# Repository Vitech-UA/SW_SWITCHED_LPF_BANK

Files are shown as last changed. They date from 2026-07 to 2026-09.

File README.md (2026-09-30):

# HF_SWITCHED_LPF_BANK

Плата перемикального банку ФНЧ для КХ-підсилювача потужністю до 250 Вт.

## Підтримувані діапазони

- 80 м (3,6 МГц)
- 40 м (7,2 МГц)
- 20 м (14 МГц)
- 15 м (21 МГц)

## Живлення (роз'єм X4)

- Напруга живлення плати: 12–24 В.
- Споживання: не більше 100 мА.

## Керування (роз'єм X3)

| Діапазон | Частота | A | B | C | D | Код ABCD |
|:---:|---:|:---:|:---:|:---:|:---:|:---:|
| 80 м | 3,5 МГц | 1 | 0 | 0 | 0 | `1000` |
| 40 м | 7 МГц | 0 | 1 | 0 | 0 | `0100` |
| 20 м | 14 МГц | 0 | 0 | 1 | 0 | `0010` |
| 15 м | 21 МГц | 0 | 1 | 1 | 0 | `0110` |

---

## Розрахунок ФНЧ для КХ-діапазонів

Для розрахунків використано онлайн-калькулятор [LC Filter Design Tool](https://markimicrowave.com/technical-resources/tools/lc-filter-design-tool/) від Marki Microwave.

### Результати розрахунків

| Діапазон | Частота розрахунку | Результат |
|:---:|:---:|:---:|
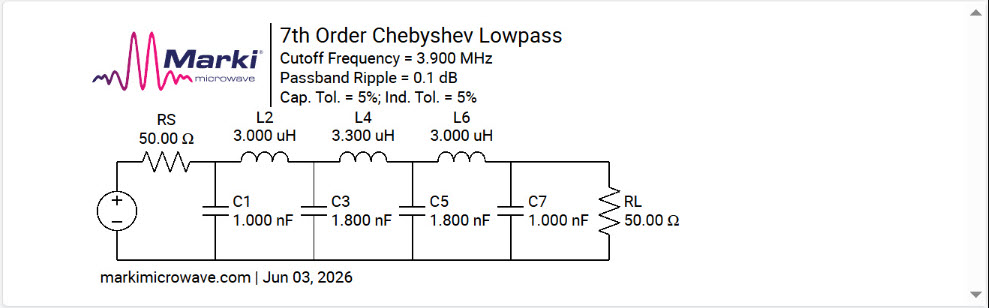
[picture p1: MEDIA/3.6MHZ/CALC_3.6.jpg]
ФНЧ 3,6 МГц
| **80 м** | 3,6 МГц |  |
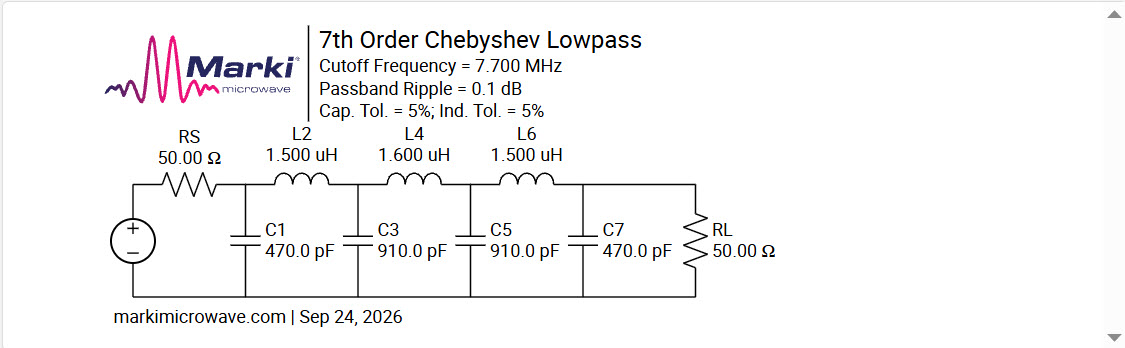
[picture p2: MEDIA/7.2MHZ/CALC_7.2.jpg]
ФНЧ 7,2 МГц
| **40 м** | 7,2 МГц |  |
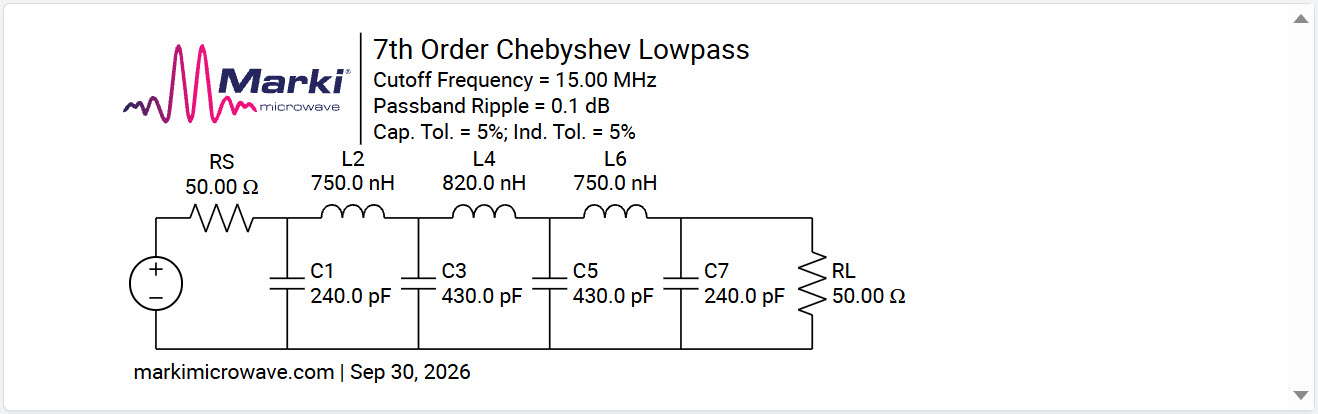
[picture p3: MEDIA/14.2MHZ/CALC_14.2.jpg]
ФНЧ 14,2 МГц
| **20 м** | 14 МГц |  |
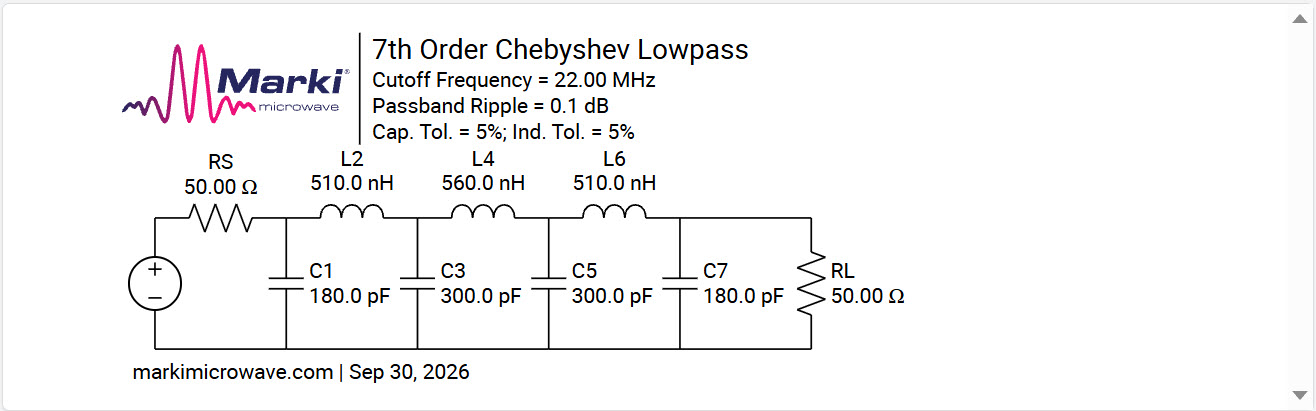
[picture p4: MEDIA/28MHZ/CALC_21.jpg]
ФНЧ 21 МГц
| **15 м** | 21 МГц |  |

---

## Зовнішній вигляд

| Верхня сторона плати | Верхня сторона без компонентів | Нижня сторона |
|:---:|:---:|:---:|
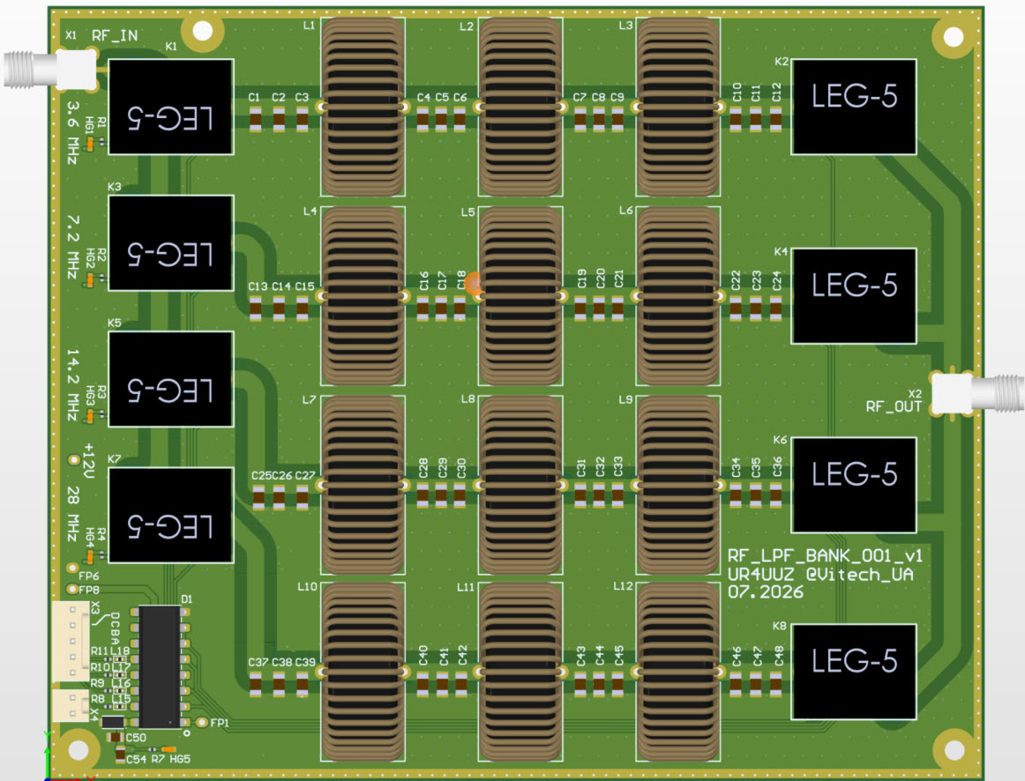
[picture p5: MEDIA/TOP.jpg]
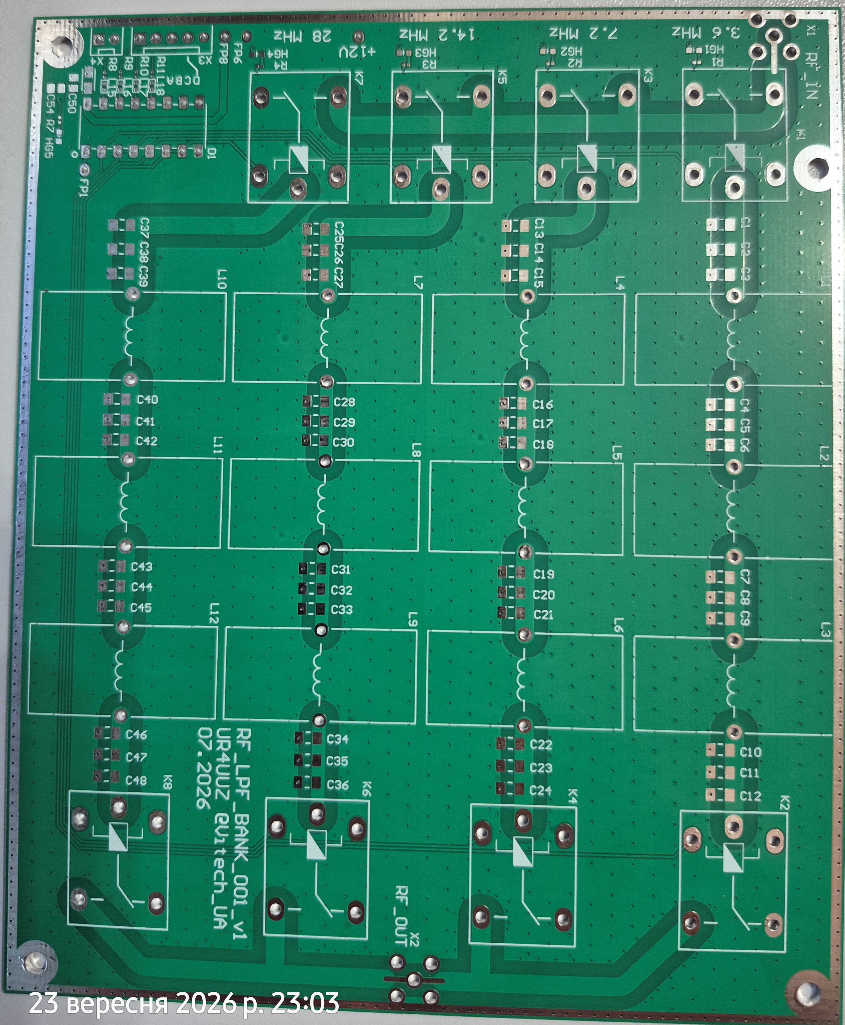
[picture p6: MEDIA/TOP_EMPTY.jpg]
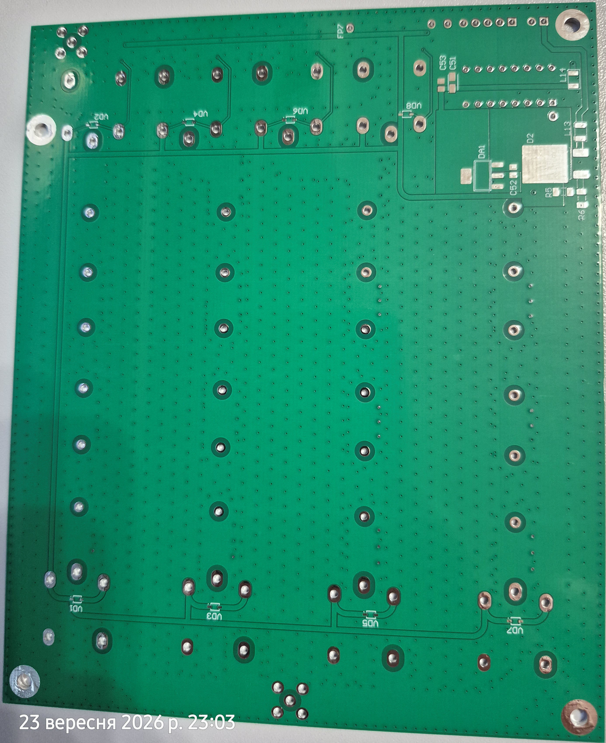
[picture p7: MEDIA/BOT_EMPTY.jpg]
|  |  |  |

## Збірка (без L та C)

| Верхня сторона | Нижня сторона |
|:---:|:---:|
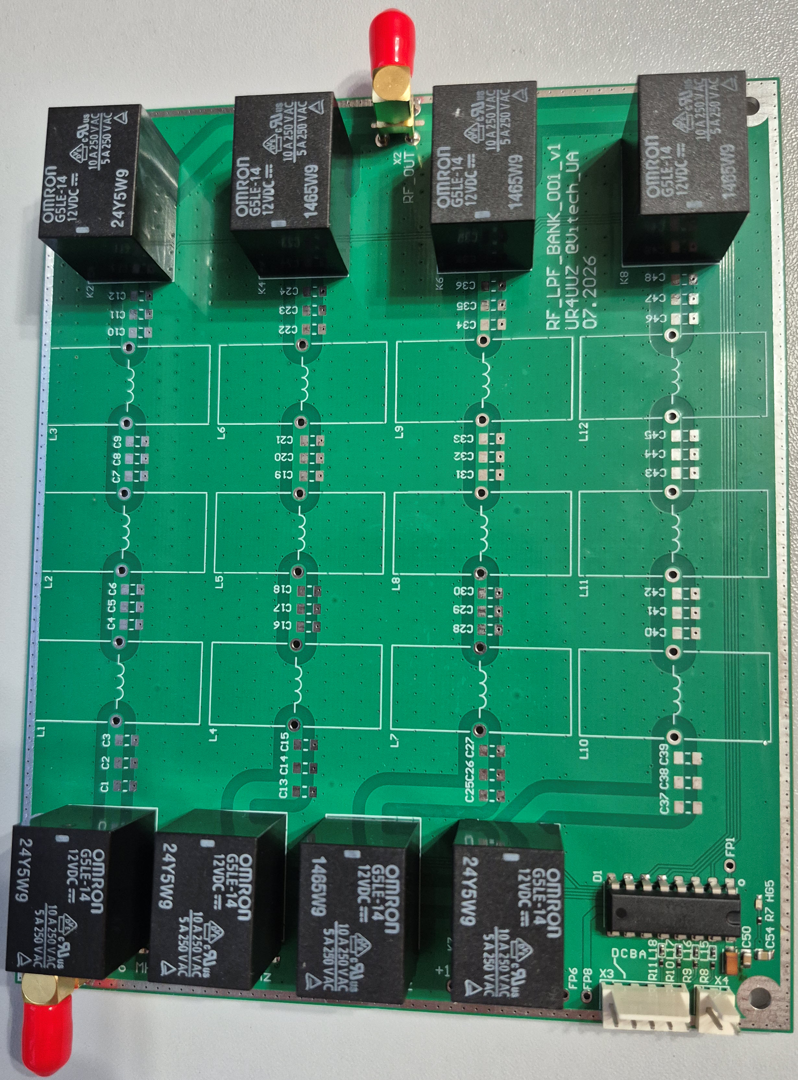
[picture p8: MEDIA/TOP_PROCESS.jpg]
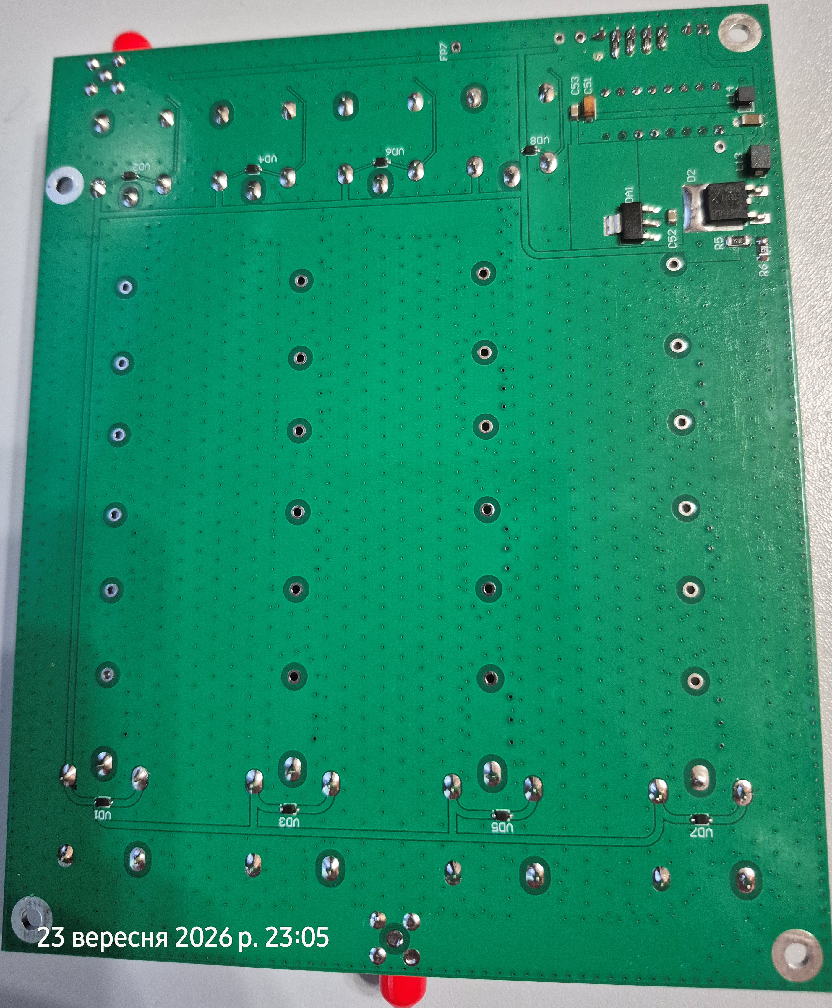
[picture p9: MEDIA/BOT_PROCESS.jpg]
|  |  |

---

## Налаштування та результати вимірювань ФНЧ

### 1. ФНЧ 80 м — 3,6 МГц

<details>
<summary><b>Переглянути налаштування та результати вимірювань</b></summary>

#### Налаштування

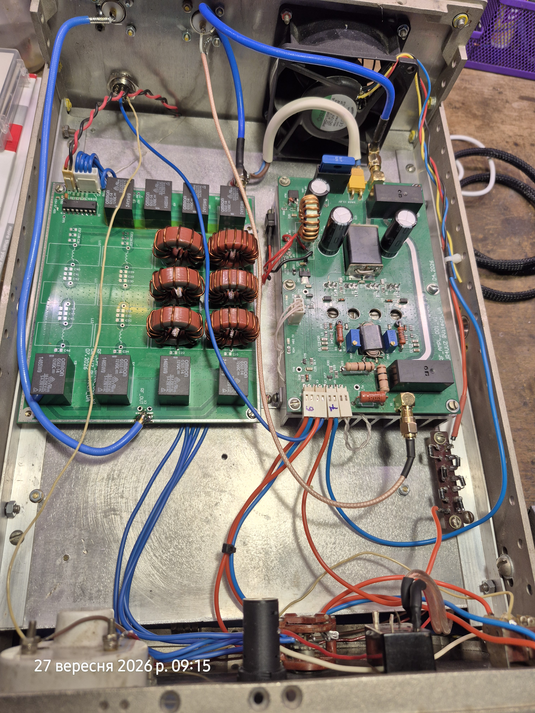
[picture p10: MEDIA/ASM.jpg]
Налаштування


#### Результати вимірювань

**S21 — Передача**

Коефіцієнт передачі у смузі пропускання 3,5–3,7 МГц не менше −0,009 дБ. На частоті 7,2 МГц — не більше −52 дБ.

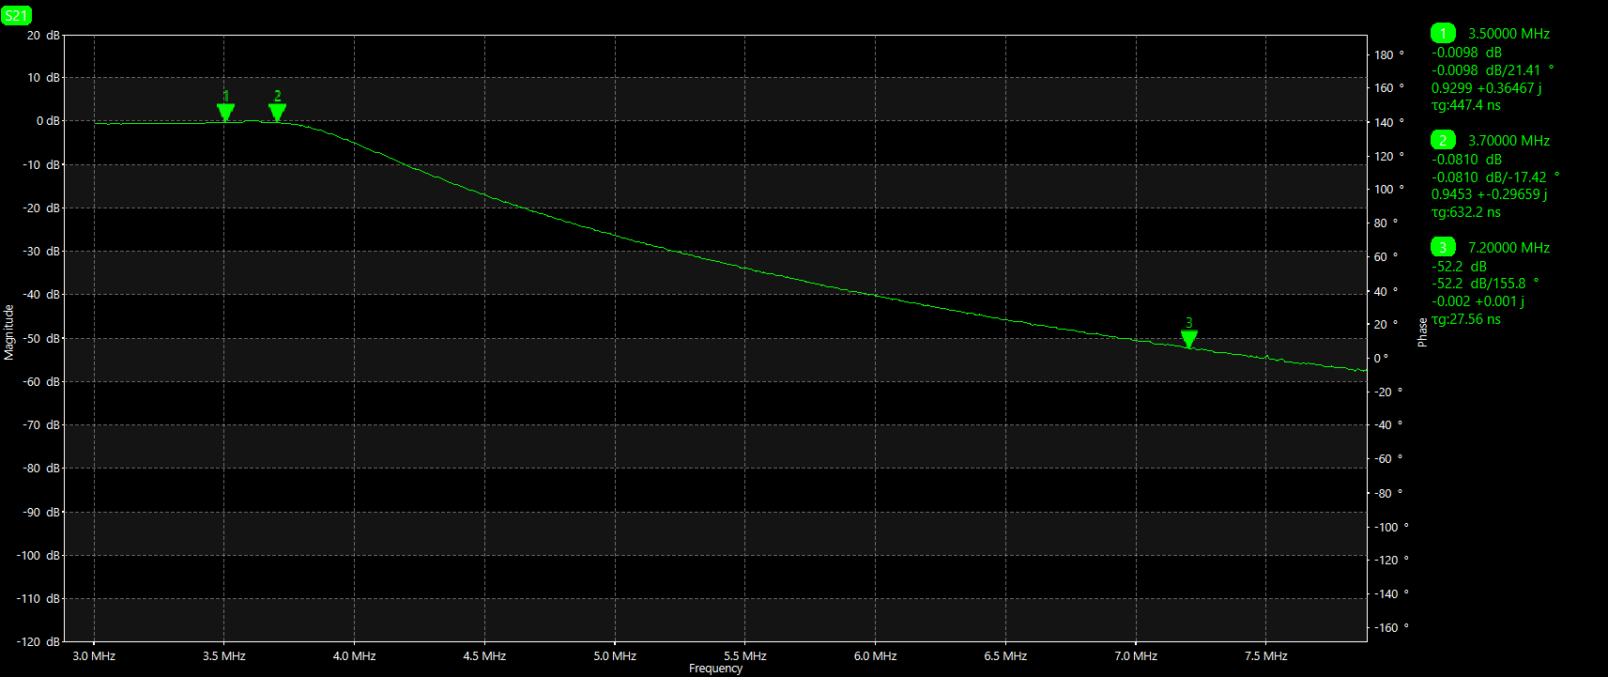
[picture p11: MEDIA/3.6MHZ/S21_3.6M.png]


**S11 — Відбиття**

КСХН у смузі пропускання 3,5–3,7 МГц не більше 1,8.

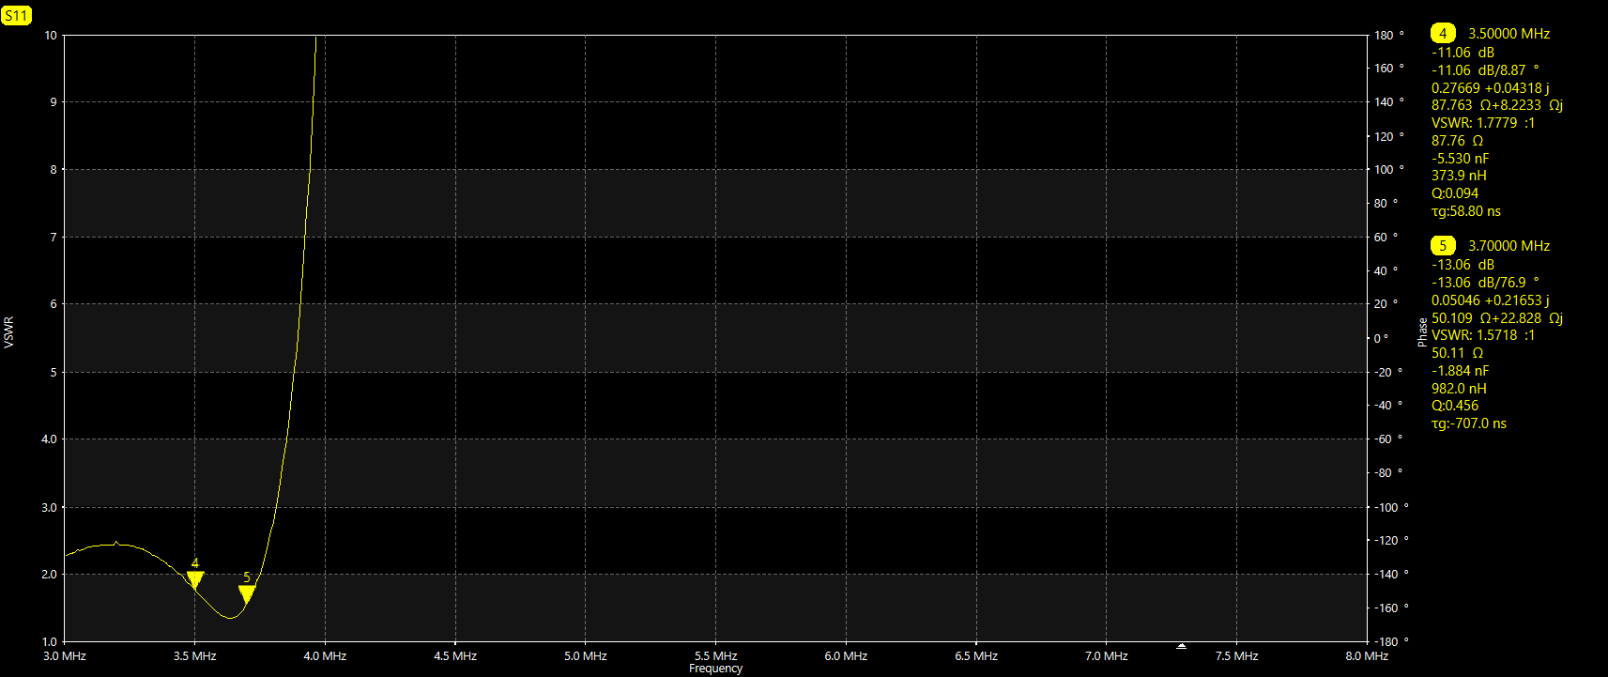
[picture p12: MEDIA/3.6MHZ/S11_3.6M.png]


</details>

### 2. ФНЧ 40 м — 7,2 МГц

<details>
<summary><b>Переглянути налаштування та результати вимірювань</b></summary>

#### Налаштування

| Етап 1 | Етап 2 |
|:---:|:---:|
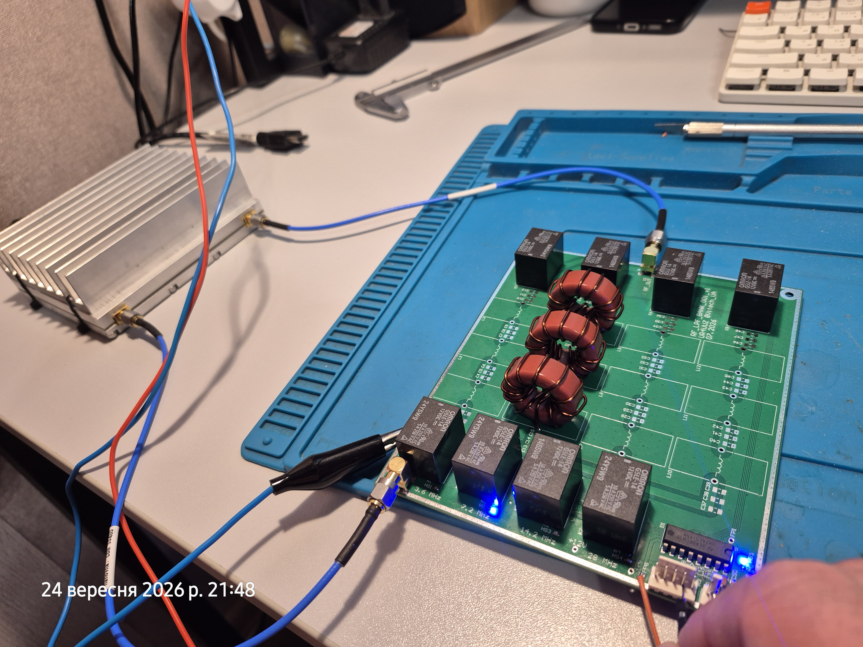
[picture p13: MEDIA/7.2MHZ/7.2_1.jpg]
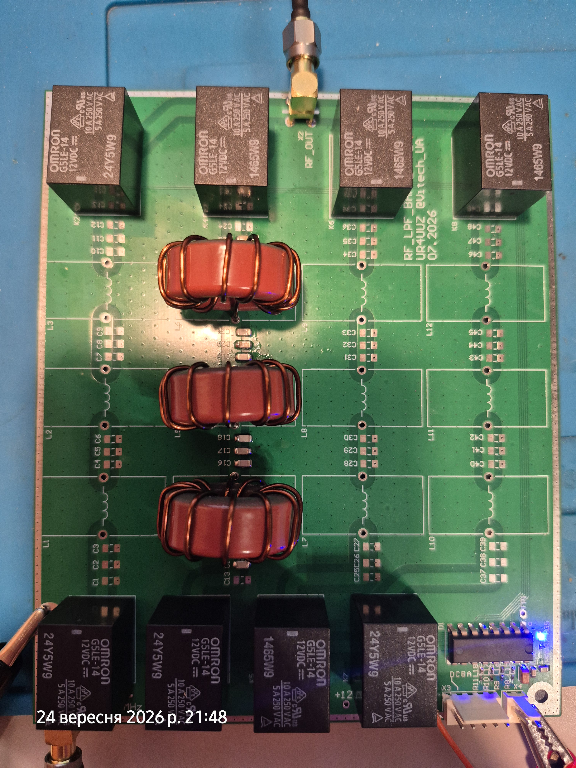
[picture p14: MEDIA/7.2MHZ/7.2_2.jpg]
|  |  |

#### Результати вимірювань

**S21 — Передача**

Коефіцієнт передачі у смузі пропускання 7–7,2 МГц не менше −0,3 дБ. На частоті 14 МГц — не більше −55 дБ.

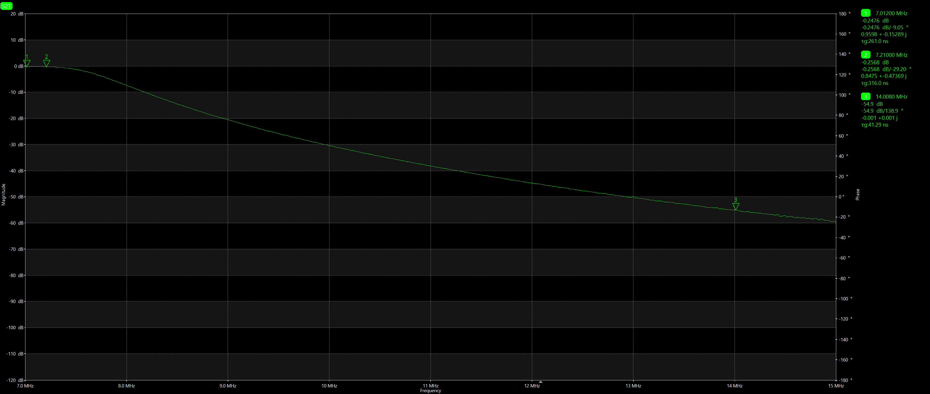
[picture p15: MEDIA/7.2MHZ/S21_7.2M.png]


**S11 — Відбиття**

КСХН у смузі пропускання 7–7,2 МГц не більше 1,3.

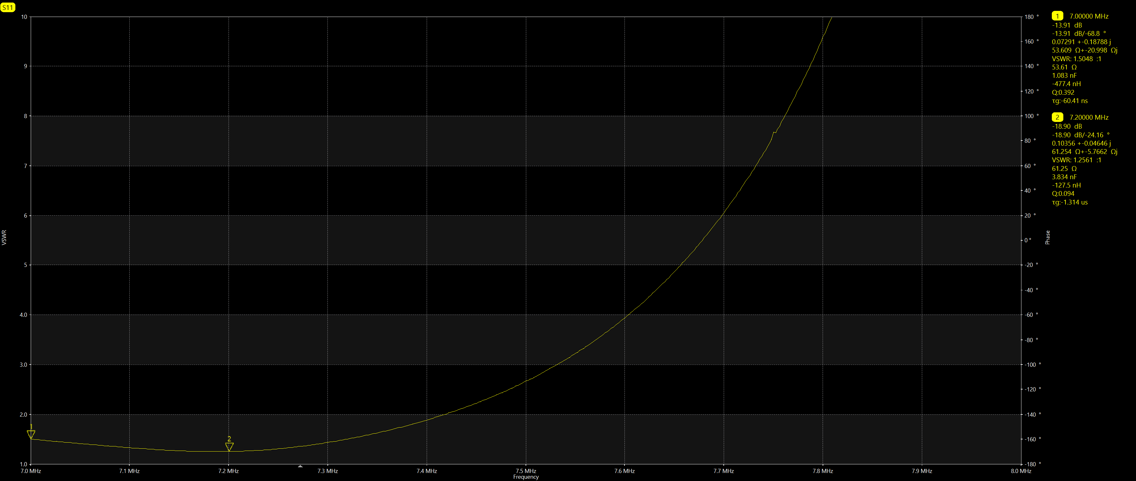
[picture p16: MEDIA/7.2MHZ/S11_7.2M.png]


</details>

### 3. ФНЧ 20 м — 14 МГц

<details>
<summary><b>Переглянути налаштування та результати вимірювань</b></summary>

#### Налаштування

| Етап 1 | Етап 2 |
|:---:|:---:|
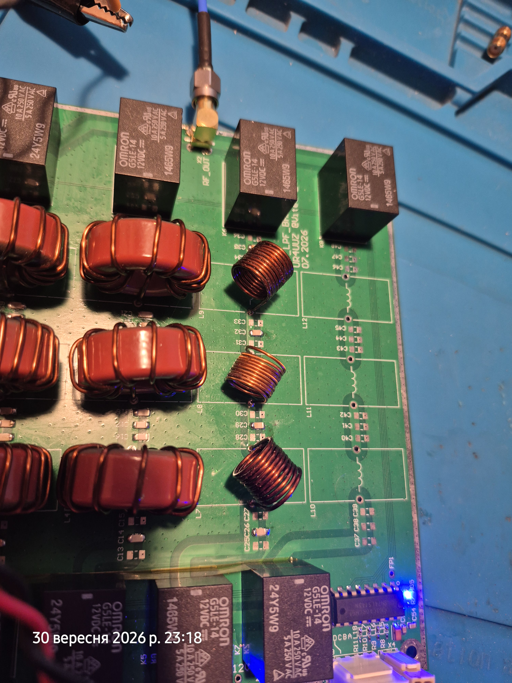
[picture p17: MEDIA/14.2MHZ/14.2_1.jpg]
|  |  |

#### Результати вимірювань

**S21 — Передача**

Коефіцієнт передачі у смузі пропускання 14–14,3 МГц не менше −0,4  дБ. На частоті 28 МГц — не більше −55 дБ.

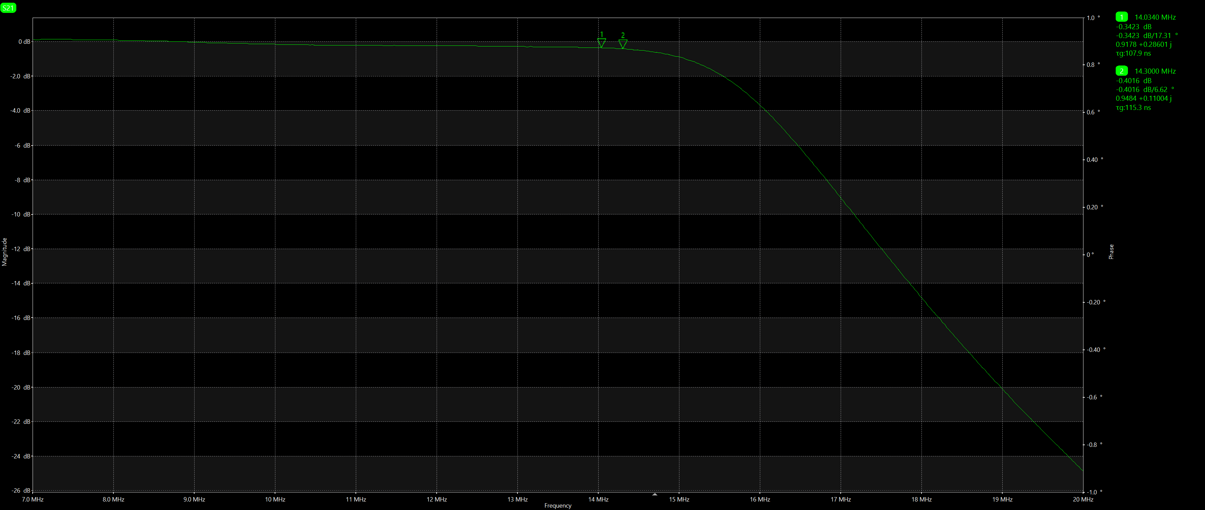
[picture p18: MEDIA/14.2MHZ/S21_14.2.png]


**S11 — Відбиття**

КСХН у смузі пропускання 14–14,2 МГц не більше 1,26.

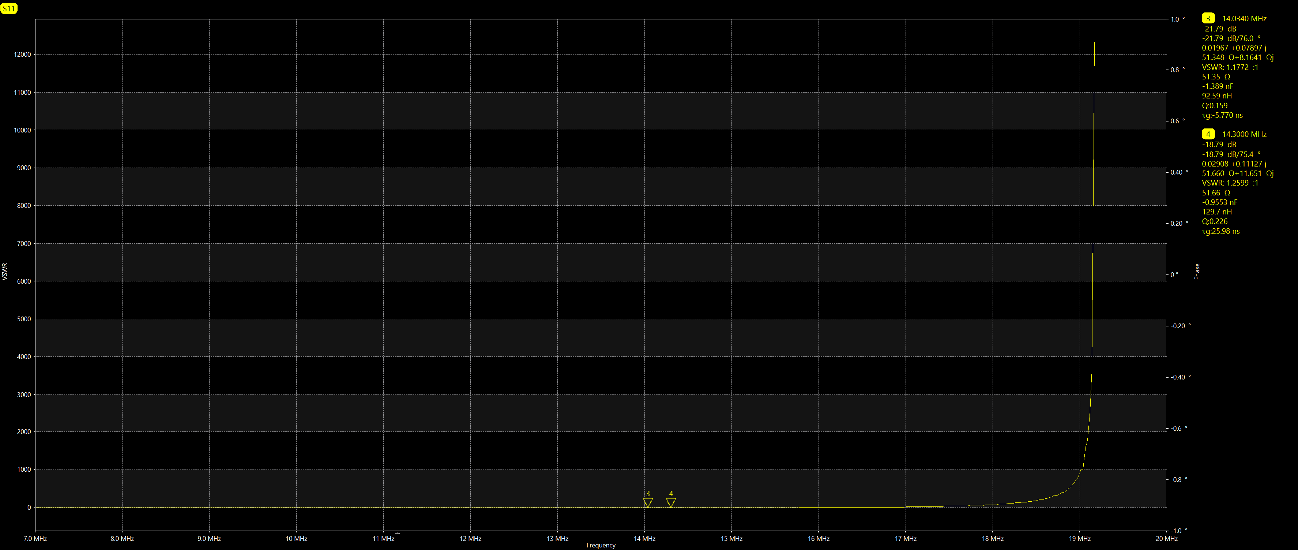
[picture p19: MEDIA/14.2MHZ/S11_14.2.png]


</details>

### 4. ФНЧ 15 м — 21 МГц

<details>
<summary><b>Переглянути налаштування та результати вимірювань</b></summary>

#### Налаштування

*Фото буде додано.*

#### Результати вимірювань

**S21 — Передача**

*Буде додано.*

**S11 — Відбиття**

*Буде додано.*

</details>

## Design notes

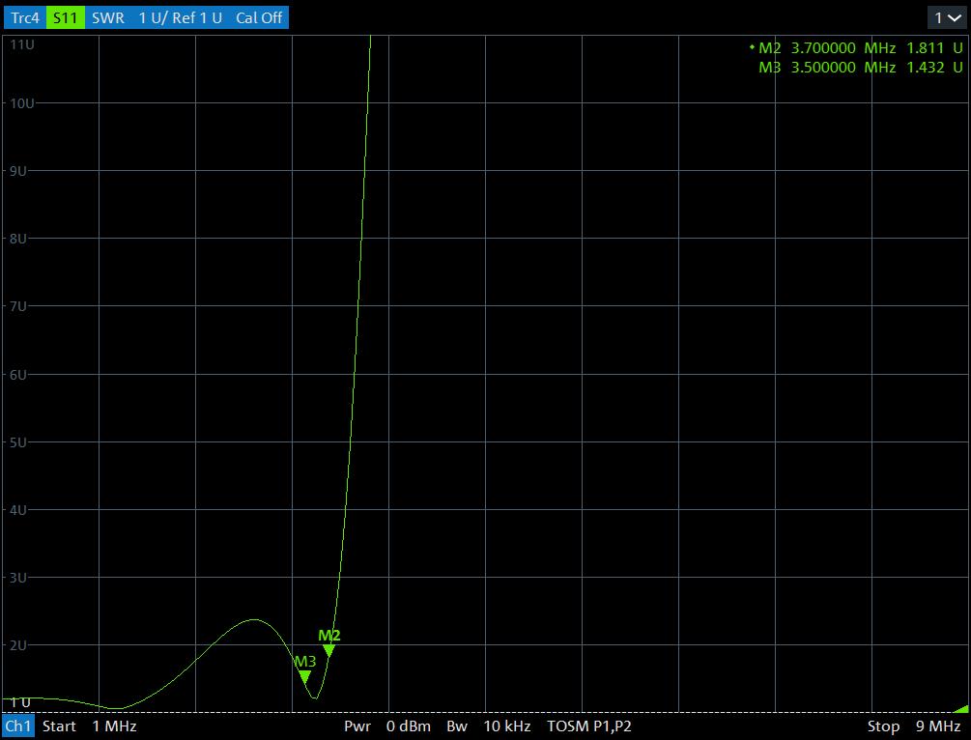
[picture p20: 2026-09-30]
MEDIA/3.6MHZ/3.6M.s11.jpeg

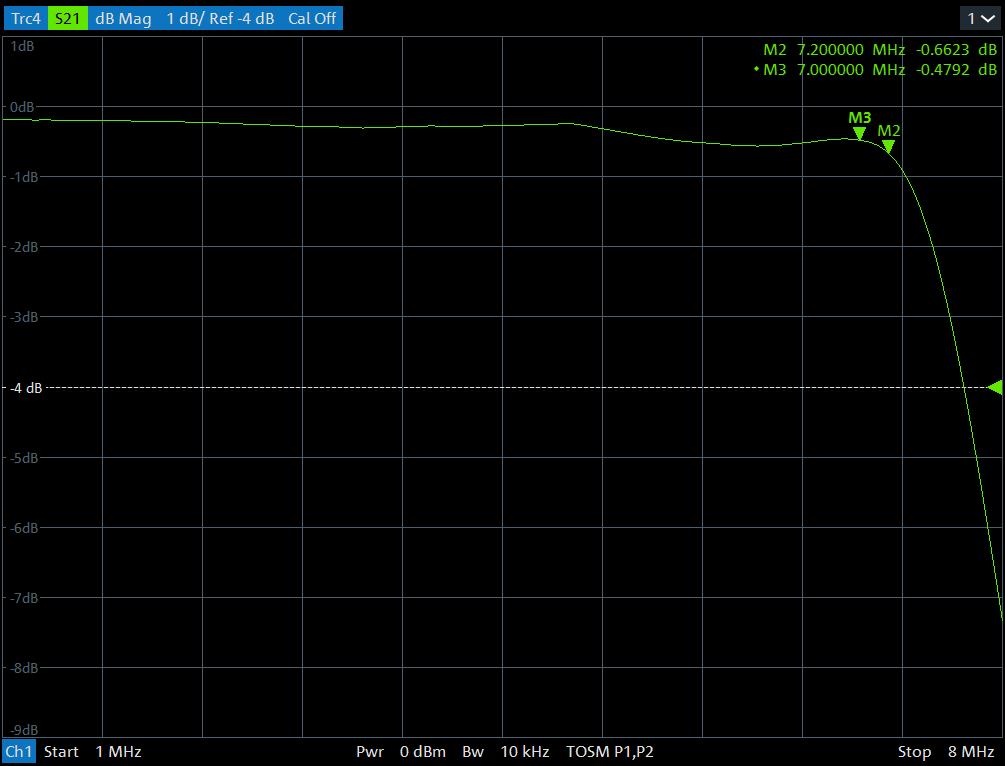
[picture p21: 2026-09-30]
MEDIA/7.2MHZ/7.2M.s21.jpeg

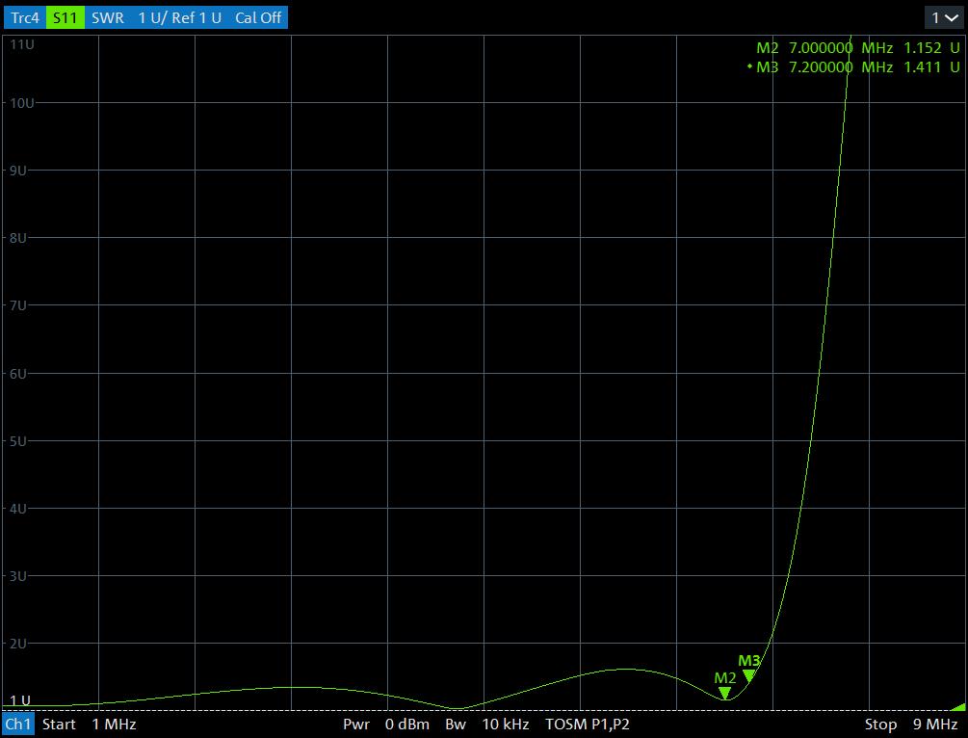
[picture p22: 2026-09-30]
MEDIA/7.2MHZ/7.2M.s11.jpeg

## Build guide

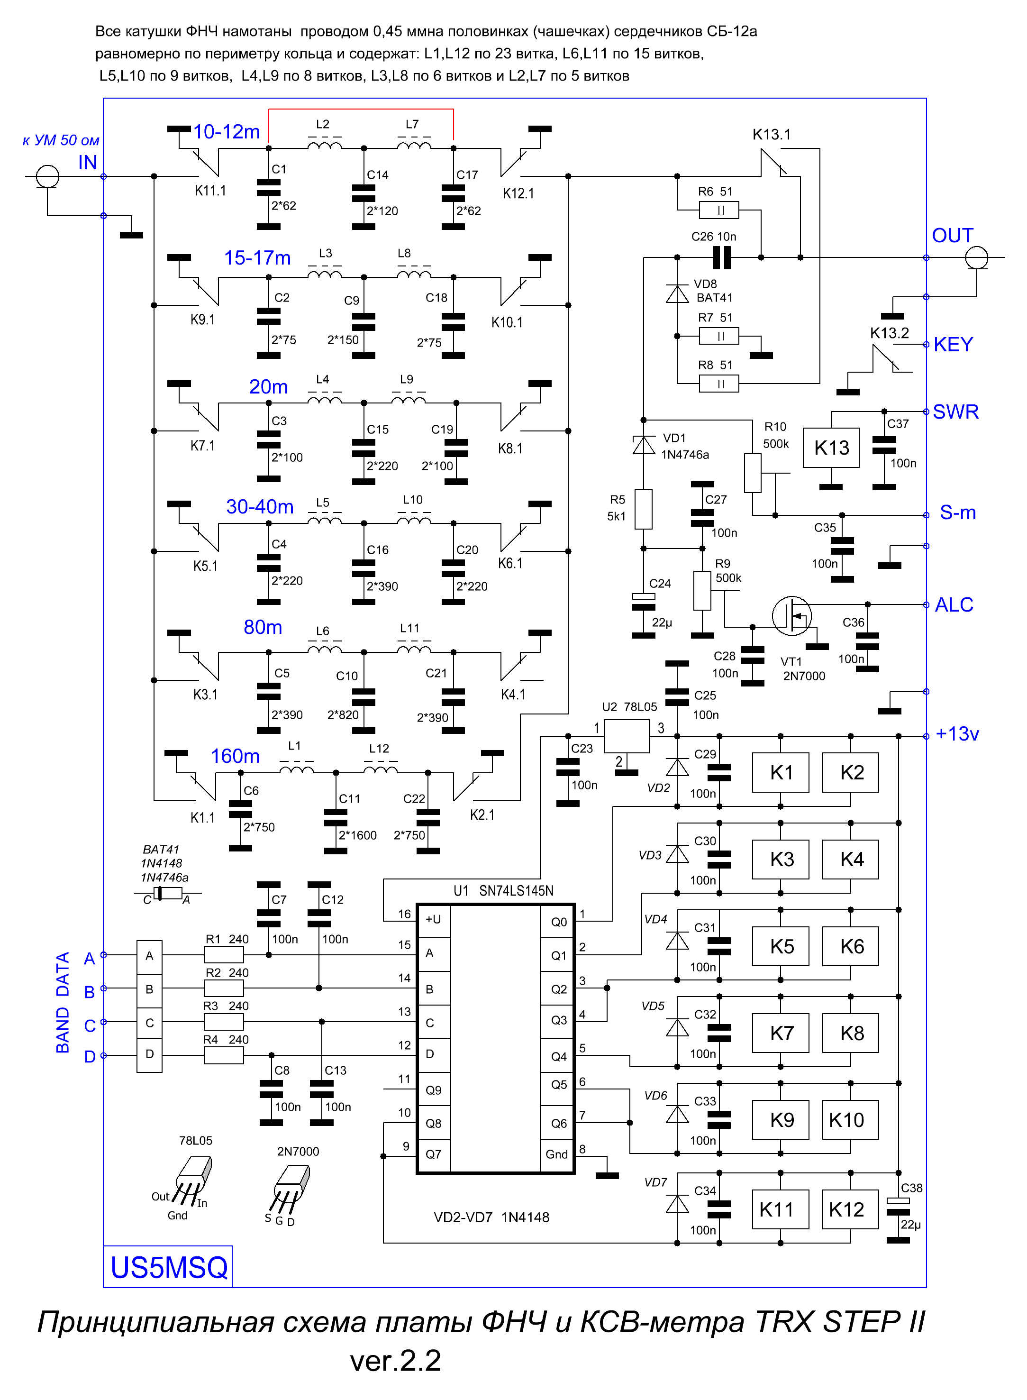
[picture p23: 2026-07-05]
SRC/Принципиальная схема платы ФНЧ TRX STEP II ver.2.2.GIF

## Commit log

2026-07-04 Розробив Е3
    [SW_SWITCHED_LPF_BANK.PrjPcb, SW_SWITCHED_LPF_BANK.SchDoc]
2026-07-05 Коднери, що не використовуються поставив в NC
    [SW_SWITCHED_LPF_BANK.SchDoc]
2026-07-05 Фікси по реле. Партномер.
    [SW_SWITCHED_LPF_BANK.SchDoc]
2026-07-05 Додав LDO 24V - 12V - 5V, прикинув споживання.
    [SW_SWITCHED_LPF_BANK.PcbDoc, SW_SWITCHED_LPF_BANK.SchDoc]
2026-07-08 Розтрасував Плату
    [SW_SWITCHED_LPF_BANK.PrjPcb, SW_SWITCHED_LPF_BANK.SchDoc]
2026-07-13 Звершив трасування. Додав лінії 50 Ом.
    [SW_SWITCHED_LPF_BANK.SchDoc]
2026-07-13 Невикористані виводи реле - на GND
    [SW_SWITCHED_LPF_BANK.PcbDoc, SW_SWITCHED_LPF_BANK.SchDoc]
2026-07-14 Зшивка GND
2026-09-06 Додав Фільтри на входи керування. Згенеровано гербери. Замовлено плати 5 шт.
    [SW_SWITCHED_LPF_BANK.PcbDoc, SW_SWITCHED_LPF_BANK.PrjPcb, SW_SWITCHED_LPF_BANK.SchDoc]
2026-09-23 Додав фото виготовленої і замонтаженої плат
2026-09-23 Додав фото
2026-09-23 Оновив опис
2026-09-23 Оновив ТУ
2026-09-23 Перейменував сигнад 10M_EN на 15М_EN
    [SW_SWITCHED_LPF_BANK.PcbDoc, SW_SWITCHED_LPF_BANK.SchDoc]
2026-09-24 Прописав партномери на ланку 7,2 МГц
    [SW_SWITCHED_LPF_BANK.SchDoc]
2026-09-24 Додав розрахунок 3.6МГц
2026-09-27 Revert "add"
    This reverts commit 79f8eac55ac5caf29ead3756314294d223dc2265.
    [SW_SWITCHED_LPF_BANK.SchDoc]
2026-09-27 Звіти налаштування 3.6M
2026-09-30 Прописав партномери для 3.6МГц
    [SW_SWITCHED_LPF_BANK.SchDoc]
2026-09-30 Додав фото 14.2
    [SW_SWITCHED_LPF_BANK.SchDoc]
2026-09-30 Прописав партномери L & C для 14MHZ
    [SW_SWITCHED_LPF_BANK.SchDoc]
